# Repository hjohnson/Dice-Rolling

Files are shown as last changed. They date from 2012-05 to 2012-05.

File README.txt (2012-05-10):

The DigiDice is an easy to use electronic die that is powered by 2 AA batteries, and uses a hardware random number generator to replace the six standard sizes of dice used in most games (D4, D6, D8, D10, D12, D20).  

Extended Version, for official writeup:

	ÒAny one who considers arithmetical methods of producing random digits is, of course, in a state of sin.Ó Ð John Von Neumann, 1951

   When I started this project, I had several design goals in mind: I wanted it to be extremely small and easy to carry, yet have 6 buttons to ÒrollÓ each of the standard sizes of die (D4, D6, D8, D10, D12, and D20). I also wanted it to based on a Random Number Generator (RNG) implemented in hardware instead of using the built in pseudo-random number generator. As those who have been watching the Show And Tell will know, IÕm proud to say that IÕve succeeded. 
   My first step was to learn as much as I could about the Random Generation process, so I could design my own generator. I found an open source design that I was able to implement. In this design, the Zener Effect of a 1.22V Zener Diode is used to generate Avalanche noise, which is then amplified through a 2n3904 NPN transistor and a pair of high-speed Op Amps, then delivered to the Microprocessor as a digital input. The microprocessor implements a debiasing algorithm known as the Von Neumann corrector to take the input noise distribution, which could have an uneven balance of 0s and 1s, and turn it into an even distribution of 0s and 1s. When the conditions of the corrector are met, the new random bit is mixed into a 32 bit number. Since this is implemented within a timer interrupt that triggers every 32 microseconds, the random number is updated extremely quickly. If you want to learn more about the RNG support circuitry or the software, check out the source files for this project. The Hardware process is described on the Schematic, and the software process is documented within the source code.
   To check that this device worked properly, I sampled the D20 option 250 times, and performed a PearsonÕs Chi-Squared test based on the null hypothesis that the source data is uniformly distributed. Suffice it to say, it passed, and I could not reject the null hypothesis. I also borrowed the method of testing from the original designer of the RNG hardware, so if youÕd like to look at the precise statistical methods, feel free to check them out at http://tinyurl.com/diyrandomgen 
   To make the device easy to use, I selected a two-digit seven-segment display, and found small tactile momentary switches that I could use for the UI. Since I wanted this project to be as small as possible, I decided to use Surface Mount devices for the RNG components and microprocessor and put them beneath the seven-segment display, on the underside of the board. I selected the Atmega8 to keep the LED driving simple (it has enough pins to drive both digits simultaneously, to keep the input switches on as few pins as possible (IÕm using a resistor ladder, and an ADC to read the result), and to have a small package to fit within the .6Ó spaced rows of pins on the seven-segment display. Because I was able to place all of the components (besides the switches and display) on the underside of the board, the top of the device is clean and simple and the PCB is kept to 1.1Ó x 1.25Ó, small enough to easily attach it to a 2xAA battery pack. Since the batteries would run out in under 10 days due to the high (~10mA) quiescent current use of the ADC and RNG circuitry, a simple power switch is included to turn power to the whole device on and off. At one-off prices, all of the components can be bought for about $10. The PCB is small, so if you buy from Laen over at DorkbotPDX (Who, by the way, awesomely accepted several last-minute design file changes, on a weekend no less) itÕs about $7 for 3 boards. 
   In short, this is a simple, easy to use artificial die. When a button is pressed, the machine generates a random number in the appropriate range, displays it on the screen for several seconds, and then turns off the display. If you use this device, you donÕt have to worry about carrying around a bag of dice, finding an even rolling surface, or losing a die. And in the process, I learned about Hardware RNGs, and designed my first mostly surface-mount PCB. This project is released as Open Hardware under the CC BY/SA License.

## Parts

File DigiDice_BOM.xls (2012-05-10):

Digi-Key Part Number | Manufacturer | Manufacturer Part Number | Description | Quantity 1 | Price | Comments
ATMEGA48A-AU-ND | ATMEL | ATMEGA48A-AU | IC MCU AVR 4K FLASH 32TQFP | 1 | 1.94 | Any in that line is fine, but *not* atmega8, I need the PCINTS
MCP6282-E/SN-ND | MICROCHIP TECHNOLOGY | MCP6282-E/SN | IC OPAMP 2.2V DUAL R-R 8SOIC | 1 | 0.96 | Note High GBWP and Slew Rate if selecting replacement.
MMBT3904FSCT-ND | FAIRCHILD SEMICONDUCTOR (VA) | MMBT3904 | TRANSISTOR GP NPN AMP SOT-23 | 1 | 0.16 | SOT23-3 version of 2n3904
ZXRE1004FFCT-ND | DIODES/ZETEX (VA) | ZXRE1004FFTA | IC VREF SHUNT PREC 1.22V SOT23-3 | 1 | 1.12 | Voltage Reference: Don't pick an "ultra-low noise" device
516-1206-5-ND | AVAGO TECHNOLOGIES US INC | HDSP-521E | LED 7-SEG 14.2MM 2DIG CA HER RHD | 1 | 1.76 | Common Anode
490-4789-1-ND | MURATA ELECTRONICS (VA) | GCM21BR72A104KA37L | CAP CER 0.1UF 100V 10% X7R 0805 | 2 | 0.12 | Passives are Jellybeans: Pick any 0805 resistor, cap, etc.
RMCF0805JT470RCT-ND | STACKPOLE ELECTRONICS INC (VA) | RMCF0805JT470R | RES 470 OHM 1/8W 5% 0805 SMD | 3 | 0.03
RMCF0805JT10K0CT-ND | STACKPOLE ELECTRONICS INC (VA) | RMCF0805JT10K0 | RES 10K OHM 1/8W 5% 0805 SMD | 3 | 0.03
RMCF0805JT100KCT-ND | STACKPOLE ELECTRONICS INC (VA) | RMCF0805JT100K | RES 100K OHM 1/8W 5% 0805 SMD | 1 | 0.03
RMCF0805JT1M00CT-ND | STACKPOLE ELECTRONICS INC (VA) | RMCF0805JT1M00 | RES 1M OHM 1/8W 5% 0805 SMD | 1 | 0.03
EG2513-ND | E-SWITCH | TL1107BF180WQ | SWITCH TACTILE SPST-NO 0.05A 12V | 6 | 0.46
2463K-ND | KEYSTONE ELECTRONICS | 2463 | HOLDER BATTERY 2CELL AA 6"LEAD | 1 | 1.32
Totals |  |  |  | 22 | 10.5

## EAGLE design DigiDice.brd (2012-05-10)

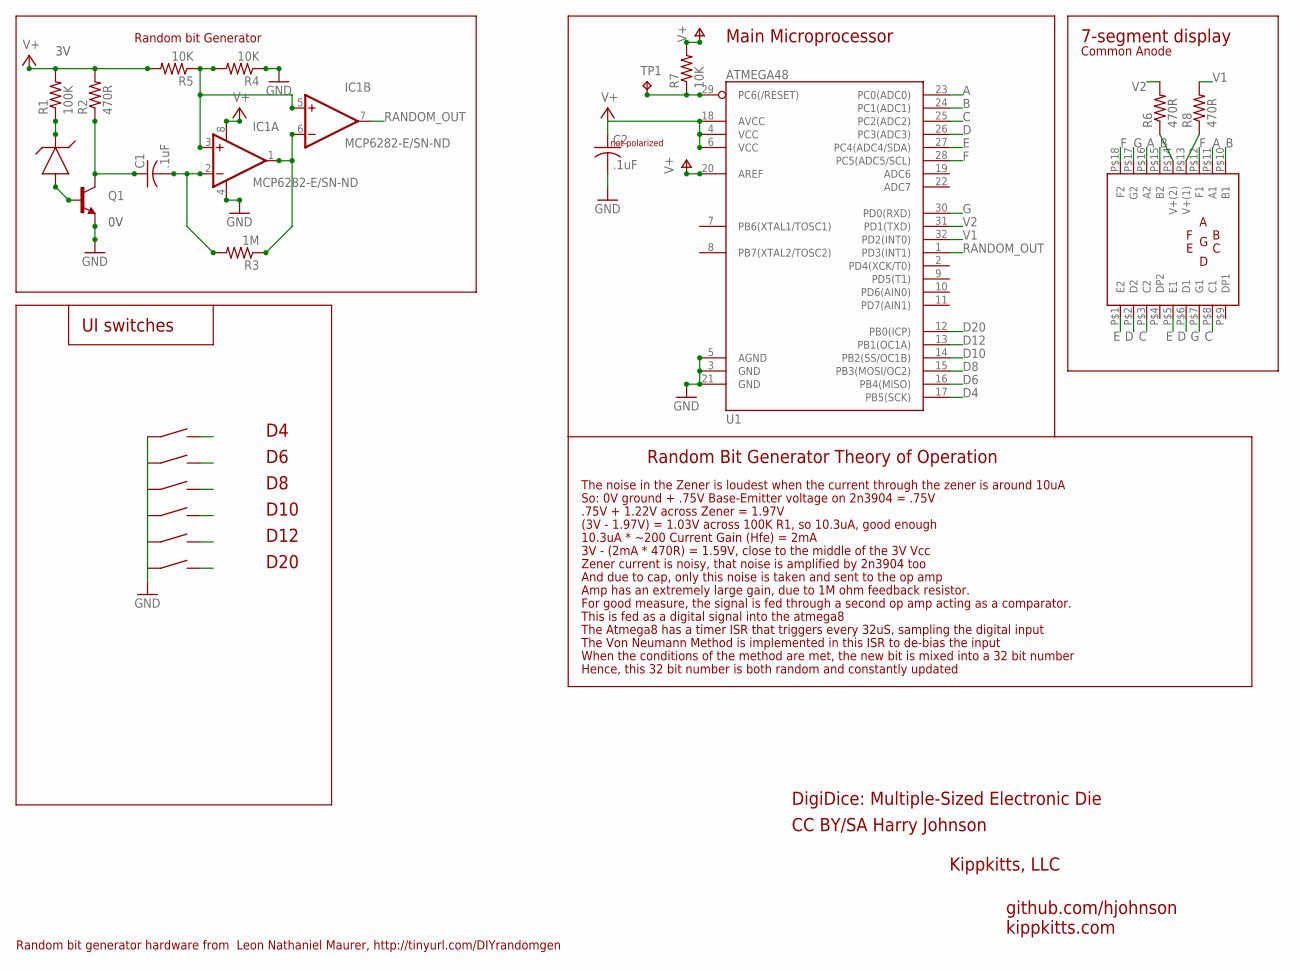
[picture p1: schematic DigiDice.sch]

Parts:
C1, C2: .1uF; C0805
IC1: MCP6282-E/SN-ND; SO08
Q1: TRANSISTOR_NPNSOT23; SOT23
R1: 100K; R0805
R2, R6, R8: 470R; R0805
R3: 1M; R0805
R4, R5, R7: 10K; R0805
SW1, SW2, SW3, SW4, SW5, SW6: SPST_SWITCH; EG2513-ND
TP1: TPB1,27; B1,27
U1: ATMEGA48; TQFP32-08
U$1: ZXRE1004FFTA; SOT23
U$2: 2DIGIT_7SEGMENT; HDSP-521E

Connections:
/RES: R7.1, TP1.TP, U1.29 (PC6(/RESET))
A: U1.23 (PC0(ADC0)), U$2.P$11 (A1), U$2.P$16 (A2)
B: U1.24 (PC1(ADC1)), U$2.P$10 (B1), U$2.P$15 (B2)
C: U1.25 (PC2(ADC2)), U$2.P$3 (C2), U$2.P$8 (C1)
D: U1.26 (PC3(ADC3)), U$2.P$2 (D2), U$2.P$6 (D1)
D4: SW1.P$2 (2), U1.17 (PB5(SCK))
D6: SW2.P$2 (2), U1.16 (PB4(MISO))
D8: SW3.P$2 (2), U1.15 (PB3(MOSI/OC2))
D10: SW4.P$2 (2), U1.14 (PB2(SS/OC1B))
D12: SW5.P$2 (2), U1.13 (PB1(OC1A))
D20: SW6.P$2 (2), U1.12 (PB0(ICP))
E: U1.27 (PC4(ADC4/SDA)), U$2.P$1 (E2), U$2.P$5 (E1)
F: U1.28 (PC5(ADC5/SCL)), U$2.P$12 (F1), U$2.P$18 (F2)
G: U1.30 (PD0(RXD)), U$2.P$7 (G1), U$2.P$17 (G2)
GND: C2.2, IC1.4 (V-), Q1.2 (E), R4.1, SW1.P$1 (1), SW2.P$1 (1), SW3.P$1 (1), SW4.P$1 (1), SW5.P$1 (1), SW6.P$1 (1), U1.3 (GND), U1.5 (AGND), U1.21 (GND)
unnamed: Q1.1 (B), U$1.2 (A)
unnamed: C1.1, Q1.3 (C), R2.1
unnamed: R1.1, U$1.1 (K)
unnamed: C1.2, IC1.2 (-IN), R3.2
unnamed: IC1.1 (OUT), IC1.6 (-IN), R3.1
unnamed: IC1.3 (+IN), IC1.5 (+IN), R4.2, R5.1
RANDOM_OUT: IC1.7 (OUT), U1.1 (PD3(INT1))
V1: R8.2, U1.32 (PD2(INT0))
V1_LED: R8.1, U$2.P$13 (V+(1))
V2: R6.2, U1.31 (PD1(TXD))
V2_LED: R6.1, U$2.P$14 (V+(2))
V+: C2.1, IC1.8 (V+), R1.2, R2.2, R5.2, R7.2, U1.4 (VCC), U1.6 (VCC), U1.18 (AVCC), U1.20 (AREF)

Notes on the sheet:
Random bit Generator
UI switches
7-segment display
Main Microprocessor
D10
D12
D20
Random bit generator hardware from Leon Nathaniel Maurer, http://tinyurl.com/DIYrandomgen
not polarized
DigiDice: Multiple-Sized Electronic Die
CC BY/SA Harry Johnson
github.com/hjohnson
Random Bit Generator Theory of Operation
The noise in the Zener is loudest when the current through the zener is around 10uA
So: 0V ground + .75V Base-Emitter voltage on 2n3904 = .75V
.75V + 1.22V across Zener = 1.97V
(3V - 1.97V) = 1.03V across 100K R1, so 10.3uA, good enough
10.3uA * ~200 Current Gain (Hfe) = 2mA
3V - (2mA * 470R) = 1.59V, close to the middle of the 3V Vcc
Zener current is noisy, that noise is amplified by 2n3904 too
And due to cap, only this noise is taken and sent to the op amp
Amp has an extremely large gain, due to 1M ohm feedback resistor.
For good measure, the signal is fed through a second op amp acting as a comparator.
This is fed as a digital signal into the atmega8
The Atmega8 has a timer ISR that triggers every 32uS, sampling the digital input
The Von Neumann Method is implemented in this ISR to de-bias the input
When the conditions of the method are met, the new bit is mixed into a 32 bit number
Hence, this 32 bit number is both random and constantly updated
Common Anode
Kippkitts, LLC
kippkitts.com

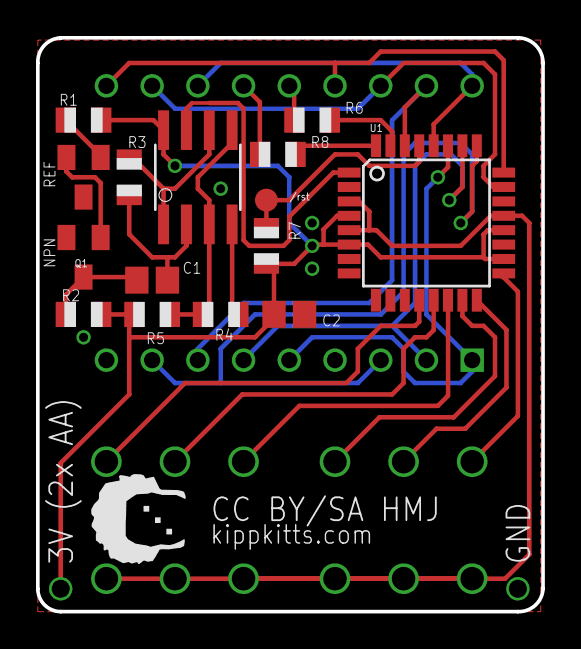
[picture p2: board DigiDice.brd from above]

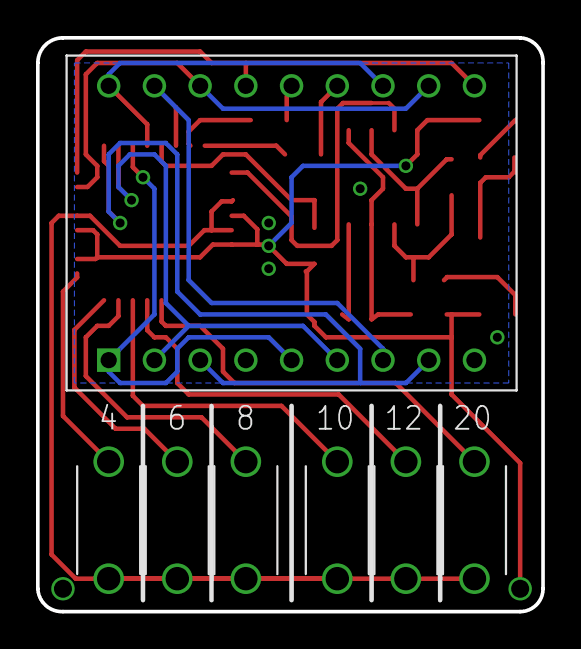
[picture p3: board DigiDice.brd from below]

Board: 2 copper layers, 28.1 x 31.9 mm, 23 parts (7 on the bottom side), 27 nets.

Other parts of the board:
U$4: TOP_DOCU_5MM

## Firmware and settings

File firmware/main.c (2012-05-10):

/* Name: main.c
 * Author: Harry Johnson
 * Firmware file for the DigiDice, produced and sold by kippkitts, LLC (http://kippkitts.com)
 * Source files currently available at https://github.com/hjohnson
 * License: CC BY/SA 
 * Uses hardware and concepts from Leon Maurer's Mini Random Number Generator: http://tinyurl.com/DIYrandomgen
 * Electronic die to replace the six standard sizes of dice used in most games.
*/

#include <avr/io.h>
#include <avr/interrupt.h>
#include <util/delay.h>
#include <avr/power.h>
#include <avr/sleep.h>

#define cycle 		randomNumber = (randomNumber >> 1) | ((((randomNumber >> 0) ^ (randomNumber >> 3)) & 1) << 24)
//this does the linear feedback shift on pool and mixes in a radnom bit
#define mixInBit(bit)	randomNumber = (randomNumber >> 1) | (((bit ^ (randomNumber >> 0) ^ (randomNumber >> 3)) & 1) << 24)
#define COUNTER_HIGH 0x7A //maximum counter value. Used to set the display timeout. 
#define COUNTER_LOW 0x12 

//Function declarations
void setupRandomGenerator(); //sets up clock for random number generator.
void setupIO();
void setupSevenSegment();

void enableSevenSegment(); //set up all of the 7-segment display pins.
void disableSevenSegment(); //set all the 7-segment display pins to high-impedance outputs.

void displayValue(uint8_t value); //display a given 2-digit value
void displayTensPlace(uint8_t value); //display 0-9 in the ten's place.
void displayOnesPlace(uint8_t value); //display 0-9 in the one's place
void rollAndDisplay(uint8_t die); //roll a value and display it, and reset the counter.



//variable declarations
const uint8_t displayMap[10] = {~0x3f,~0x06, ~0x5B, ~0x4F, ~0x66, ~0x6D, ~0x7D, ~0x07, ~0x7F, ~0x6F}; //7-segment display (gfedcba) mapping. Common anode: 0 is on. 
const uint8_t dieMax[6] = {20, 12, 10, 8, 6, 4}; //6 values of max dice count.
volatile uint32_t randomNumber=0b1010101010101010101010101; //32 bit random number, always being refreshed.
volatile uint8_t lastbit = 255; //what the last input digit was, or -1 if we want to force a start-over. (after outputting a bit)

volatile uint8_t currentlyDisplaying = 0; //what value the LED is currently displaying. 
volatile uint8_t whichDigit = 0; //0 for one's place, 1 for ten's place.

int main(void)
{
    clock_prescale_set(0); 
    WDTCSR |= (1<<WDCE) |(1<<WDE); //enable changes to watchdog timer register
    WDTCSR = 0; //disable watchdog timer.
    cli(); //temporarily disable interrupts.
    power_adc_disable(); //power down a load of stuff to save power.
    power_spi_disable();
    power_twi_disable();
    power_usart0_disable();
    setupIO(); //switches, seven segment display pin.
    setupRandomGenerator(); //timer register setup
    setupSevenSegment(); //timers for the seven-segment displays
    disableSevenSegment(); //make sure we aren't driving the pins
    sei(); //enable interrupts;
    for(;;) {
    
    }
    return 0;   /* never reached */
}


ISR(TIMER0_OVF_vect) { //triggering every 32 microseconds or so. 
    if((lastbit != ((PIND>>3)&1)) && (lastbit != 255)) { //if there are 2 bits, and they aren't equal
        mixInBit(lastbit);
        lastbit = 255; //and start the sequence of capturing another 2 bits.
    } else {
        lastbit = (PIND>>3)&1; //capture the first bit
    }
}

ISR(TIMER1_COMPA_vect) { //LED timeout, every 4 seconds or so. turn off the display and put everything back to sleep.
    TCNT1H = 0; //reset the timer 1 counter.
    TCNT1L = 0;
    TIMSK2 &= ~(1<<TOIE2);
    disableSevenSegment(); //turn off the display.
    PCIFR |= (1<<PCIF0);
    PCICR |= (1<<PCIE0); //re-enable the pin change interrupt to allow another switch.
    currentlyDisplaying = 0; //and note that we're not currently displaying anything.
    clock_prescale_set(6); //drop the clock speed down to 125Khz while the the device is off to save power.
}

ISR(TIMER2_OVF_vect) { //triggering on 120Hz.
    if(whichDigit == 0) { //display the one's place
        displayOnesPlace(currentlyDisplaying);
        whichDigit = 1; //display the ten's place next.
    } else { //display the ten's place
        displayTensPlace(currentlyDisplaying);
        whichDigit = 0; //display the one's place next.
    }
}

ISR(PCINT0_vect) { //one of the switches was pressed. (high to low)
    PCICR &= ~(1<<PCIE0); //disable the pin change interrupt (debouncing hack).
    PCIFR |= (1<<PCIF0); //clear the flag so it doesn't retrigger on bounce, just in case.
    clock_prescale_set(0); //bring the clock speed back up to the full 8MHz. 
    uint8_t ii = 0;
    while(ii<6) { //which of the switches was pressed?
        if((PINB & (1<<ii)) == 0) {//active low pin
            rollAndDisplay(dieMax[ii]);
        }
    ii++;
    }
}


void setupIO() {
    DDRB = 0; //all of port B input
    PORTB = 0x3F; //turn on the pull-up resistors on the first 6 lines (switches)
    PCMSK0 = 0x3F; //turn on pin change interrupts for the first 6 lines.
    PCICR = (1<<PCIE0); //Enable that pin change interrupt bus.
    
    //Seven-Segment displays. 
    PORTC &= ~(0x3F); //PC0-5 low. 
    DDRC |= 0x3F; //PC0-PC5 outputs; 
    DDRD |= 0x07; //PD0-2 output, otherwise inputs;
    PORTD &= ~(0x07); //bring everything low, so no displays will be on. 
}

void setupRandomGenerator() {
    DDRD &= ~(1<<3); //PORTD3 input.
    PORTD &= ~(1<<3); //with no pull-up resistor.
    TCNT0 = 0; //reset counter 0
    TCCR0B = 1; // internal clock, no prescaling for random number updater.
    TIMSK0 |= (1<<TOIE0); //enable overflow register for counter 0. Output compare register on counter 1;
}

//7-segment LED code.
void rollAndDisplay(uint8_t die) { //roll a value, display it on the screen, and reset the timing counter.
    displayValue((randomNumber%die)+1); //generate a new number and display it.
}

void setupSevenSegment() {
    TCNT1H = 0; //reset the timer 1 counter.
    TCNT1L = 0; 
    
    OCR1AH = COUNTER_HIGH; //16 bit maximum counter. 
    OCR1AL = COUNTER_LOW; 
    TCCR1A = 0; //no PWM, etc.
    TCCR1B = (1<<CS12) | (1<<CS10); // clock/1024 prescalar for 7-segment timeout.
    TIMSK1 |= (1<<OCIE1A);
    
    TCCR2A = 0;
    TCCR2B = (1<<CS22) | (1<<CS21); //main frequency divided by 256. With additional div by 256 gives 122 Hz update rate, more than fast enough.
}
              
void enableSevenSegment() {    
    TCNT1H = 0; //reset the timer 1 counter: 4s countdown.
    TCNT1L = 0;
    TIMSK2 |= (1<<TOIE2); //enable timer 2: POV timer
    TCNT2 = 0;
}

void disableSevenSegment() {
    PORTC = 0;
    PORTD &= ~0x07;
    TIMSK2 &= ~(1<<TOIE2); //disable the timer running the display.
}
              
void displayValue(uint8_t value) { //display a 2-digit value on the seven segment.
    enableSevenSegment();
    
    if(value<100) { //2 digit display, check just in case.
        currentlyDisplaying = value;
    } 
}

void displayTensPlace(uint8_t value) { //display the value in the ten's place.
    uint8_t bitMask = displayMap[(currentlyDisplaying-(currentlyDisplaying%10))/10];
    
    PORTD &= ~(1<<2); //turn off the one's place
    PORTD |= (1<<1); //turn on the ten's place.
    
    PORTC = bitMask & 0x3F; //write the output value to the pins.
    PORTD |= (bitMask >>6)& 0x01;
    PORTD &= (0xFE | ((bitMask >>6)& 0x01));
}

void displayOnesPlace(uint8_t value) { //display the value in the one's place.
    uint8_t bitMask = displayMap[currentlyDisplaying%10];
    
    PORTD |= (1<<2); //turn on the one's place
    PORTD &= ~(1<<1); //turn off the ten's place.
    
    PORTC = bitMask & 0x3F;
    PORTD |= (bitMask >>6)& 0x01;
    PORTD &= (0xFE | ((bitMask >>6)& 0x01));
}

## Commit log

2012-02-12 UNTESTED: Rolling of multiple different size of dice, output on a 2-digit seven segment display.
    Board, schematic, and firmware. All currently untested.
    [D&D_dice_1.brd, D&D_dice_1.sch]
2012-02-19 Board, code improvement.
    Optimized the code, and improved the board a bit.
    [D&D_dice_1.brd, D&D_dice_1.sch]
2012-03-03 Major commit: TESTED
    Boards re-jiggered with bigger 0805 pads, because the small ones were
    nightmarish. Code also much improved: It now actually works!
    [D&D_dice_1.brd, D&D_dice_1.sch]
2012-03-03 Slight tweaks to the board to make it easier to solder.
    [D&D_dice_1.brd]
2012-03-25 Added test pads for reset, lightly shifted around a few resistors.
    [BOM.xls, D&D_dice_1.brd, D&D_dice_1.sch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]
2012-03-26 Added a whole bunch of explanatory text to the schematic.
    Theory of operation, mainly.
    [D&D_dice_1.sch]
2012-03-26 Rotated a capacitor to make schematic look better, and added the schematic pdf.
    [D&D_dice_1.brd, D&D_dice_1.sch]
2012-03-26 Added schematic jpeg.
2012-05-10 MAJOR COMMIT: New Version of Project
    Officially Renamed to DigiDice, produced by kippkitts (kippkitts.com)
    Changed board layout to remove need for power switch, hearty change in
    code to accompany, now only 2.4-2.8mA quiescent.
    [BOM.xls, D&D_dice_1.brd, DigiDice.brd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]

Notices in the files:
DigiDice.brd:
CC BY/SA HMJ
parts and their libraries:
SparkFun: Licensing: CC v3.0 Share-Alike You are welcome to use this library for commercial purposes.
